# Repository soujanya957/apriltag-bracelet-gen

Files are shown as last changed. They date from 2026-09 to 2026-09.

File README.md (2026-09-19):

# apriltag-bracelet-gen

Multicolor-printable AprilTag links for a snap-together bracelet. Takes any
chain-link design (as a STEP file), stretches its flat spine to fit a real
AprilTag, and outputs a body STL (light filament) plus an insert STL (black)
per link. The joint ends are left untouched, so tag links snap into the
original, unmodified links.

Built for wrist-worn fiducial tracking (anchoring egocentric-video hand pose
to a known frame for imitation-learning data), but nothing here is specific
to that.

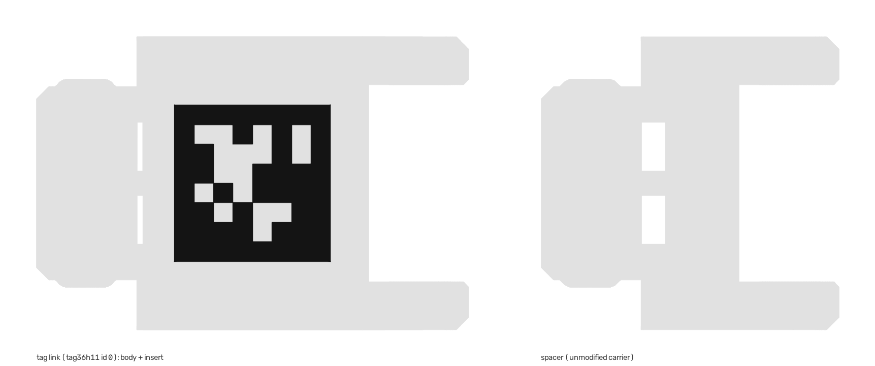
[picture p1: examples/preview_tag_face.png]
tag link next to an unmodified spacer link, seen from the tag face


*Left: generated tag link (tag36h11 id 0), light body with the black insert
flush in its pockets. Right: the unmodified carrier, exported as the spacer.*

## Quick start

```
uv venv --python 3.11 .venv && uv pip install --python .venv/bin/python -r requirements.txt
python3 -m link_gen.cli generate --carrier carriers/chainlink_v10.step \
  --profile carriers/chainlink_v10.profile.json --family tag36h11 --wrist both
```

## Docs

- [Setup](docs/setup.md) — install, get a carrier link
- [Run](docs/run.md) — generate, options, verify, choosing family/size/ids
- [Printing](docs/printing.md) — Bambu Studio multicolor workflow
- [Detection](docs/detection.md) — family, ids, pose size, `metadata.json`
- [Carriers](docs/carriers.md) — calibrate a profile for a different link design

`examples/` has one finished link (id 0 body + insert) and its metadata, to
try the print workflow without installing anything.

## Layout

```
link_gen/
  cli.py              generate / families commands
  geometry.py         CarrierProfile + cut/stretch/pocket CAD logic
  tag_source.py       fetches + caches official AprilTag bitmaps
  metadata.py         writes metadata.json per generated set
  verify.py           decodes generated inserts with a real detector
  profile_finder.py   scans a new carrier STEP to calibrate a profile
carriers/
  *.profile.json      calibration per carrier (committed)
  *.step              your carrier files (gitignored)
docs/                 guides linked above
examples/             one generated link + preview image
outputs/              generated sets (gitignored)
```

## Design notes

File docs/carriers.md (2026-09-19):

# Using a different carrier link

The tool assumes:

- both joint ends sit on either side of a flat "spine" along the carrier's
  local **X axis**;
- the spine's Y/Z cross-section is a plain constant prism (not tapered or
  filleted) across `[x_cut_left, x_cut_right]`.

## Calibrate a profile

```
python3 -m link_gen.profile_finder path/to/your_link.step
```

This slices the solid every 0.5 mm along X and prints the Y/Z cross-section
at each slice. Find the contiguous run where the cross-section stops
changing: that's the spine. Pick `x_cut_left` / `x_cut_right` safely inside
that run (not on a boundary row) and read `spine_y_min/max` and
`spine_z_min/max` off that row. Save as `carriers/your_link.profile.json`:

```json
{
  "x_cut_left": 0.5,
  "x_cut_right": 7.5,
  "spine_y_min": -12.0,
  "spine_y_max": 12.0,
  "spine_z_min": -6.0,
  "spine_z_max": 0.0,
  "solid_index": 0,
  "tag_face": "z_min"
}
```

`solid_index` picks which solid in the STEP file is the link, if it has
several.

## tag_face

Which spine face (`z_max` or `z_min`) ends up facing outward once the links
are snapped into a loop depends on the hinge design and is not derivable from
the STEP file. Generate and print one link; if the tag ends up on the inside,
flip `tag_face` in the profile and regenerate. `--tag-face` on the CLI
overrides it for one run. `chainlink_v10` needs `z_min`.

## How the geometry is built

1. Cut the carrier at `x_cut_left` and `x_cut_right`. Both joint ends are
   kept exactly as-is, so the result stays snap-compatible with unmodified
   links.
2. Bridge them with a new flat box, `extra_length` mm longer than the
   original spine.
3. Fetch the real bitmap for the requested family/id from
   [AprilRobotics/apriltag-imgs](https://github.com/AprilRobotics/apriltag-imgs)
   and cut a pocket into the tag face for every black module. Build a
   matching insert solid that fills those pockets flush.

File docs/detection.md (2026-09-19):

# Detecting the printed tags

Every generated folder has a `metadata.json` with what another machine needs.
The three values that matter:

| | tag36h11 at 16 mm (defaults) |
|---|---|
| **family** | `tag36h11` |
| **ids** | left wrist 0-7, right wrist 20-27 |
| **pose tag size** | **12.8 mm** — the black border square, *not* the 16 mm footprint (the outer 1.6 mm ring is white quiet zone). Confirm with calipers on a print. |

No key or code beyond that: AprilTag families are public and built into every
detector.

```python
# pupil-apriltags
from pupil_apriltags import Detector
det = Detector(families="tag36h11")
det.detect(gray, estimate_tag_pose=True, camera_params=(fx, fy, cx, cy), tag_size=0.0128)

# OpenCV ArUco (tag16h5 / tag25h9 / tag36h11 only)
d = cv2.aruco.getPredefinedDictionary(cv2.aruco.DICT_APRILTAG_36h11)   # markerLength=0.0128

# apriltag_ros
# tag_family: tag36h11
# standalone_tags: [{id: 0, size: 0.0128}, ...]
```

## metadata.json fields

- `generator`: git commit and the exact command line that produced the set.
- `carrier`: the STEP name, the profile used, and `spacer_file` (relative
  path to the plain-link STL).
- `link_geometry_mm`: footprint, module size, extra length, pocket depth,
  tag face.
- `detection`: family, ids, `pose_tag_size_mm`, the OpenCV dictionary name,
  and ready-to-paste snippets for pupil-apriltags / apriltag_ros / OpenCV.
- `tags[]`: files and the exact bitmap cut for each id (row 0 = top, as a
  camera sees the tag face).
- `verification`: written by `link_gen.verify`; per-id decode result and
  decision margin.

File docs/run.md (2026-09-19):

# Generate links

```
python3 -m link_gen.cli generate \
  --carrier carriers/chainlink_v10.step \
  --profile carriers/chainlink_v10.profile.json \
  --family tag36h11 \
  --wrist both
```

Writes:

```
outputs/
  spacer_chainlink_v10.stl   # unmodified carrier link, once per run
  left_wrist/                # ids 0-7:   *_body.stl, *_insert.stl, manifest.csv, metadata.json
  right_wrist/               # ids 20-27: same
```

## Options

| flag | default | meaning |
|---|---|---|
| `--wrist left\|right\|both` | `both` | which set(s) to write; each goes in `<out-dir>/<wrist>_wrist/` |
| `--ids` | left `0-7` | ids for the left (or only) wrist: range `0-7`, list `0,2,5`, or one id |
| `--right-ids` | `20-27` | ids for the right wrist |
| `--tag-size` | `16` | full tag footprint in mm, quiet zone included; must fit in `spine_len + extra_length` and `spine_width` |
| `--extra-length` | `11` | mm added to the spine. Tag links are longer than plain links; alternate with spacers to size the band |
| `--pocket-depth` | `0.4` | insert thickness in mm; 0.3–0.5 for a 0.4 mm nozzle |
| `--tag-face z_max\|z_min` | from profile | which spine face gets the tag; see [carriers.md](carriers.md) |
| `--out-dir` | `outputs` | output root |

`python3 -m link_gen.cli families` lists the supported families.

## Verify

Rasterizes each insert as a camera would see the printed face and runs a real
AprilTag detector on it. Catches mirroring or module-size mistakes before you
print. Results are written into that folder's `metadata.json`.

```
python3 -m link_gen.verify outputs/left_wrist
python3 -m link_gen.verify outputs/right_wrist
```

## Choosing a family, size, and ids

- `tag36h11` is the safe default: best false-positive rejection, which
  matters when footage is processed unsupervised.
- `tag25h9` has a simpler pattern; worth trying if motion blur is the limit
  (fast wrist movement, camera close and moving).
- Keep modules ≥ ~1.2 mm on a 0.4 mm nozzle. A 10×10 family at 16 mm gives
  1.6 mm modules; below ~12 mm total you're fighting print resolution.
- Give every link a unique id and reserve a separate block per wrist
  (left 0-7, right 20-27) so one visible tag tells you which wrist it is.

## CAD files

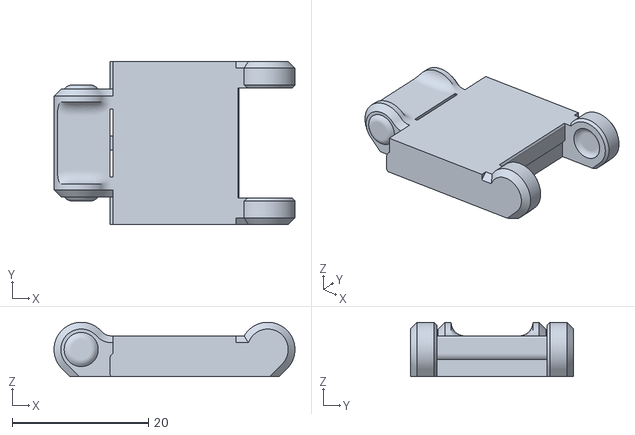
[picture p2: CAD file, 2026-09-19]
examples/link_tag36h11_000_body.stl
35.4 x 24.0 x 8.00

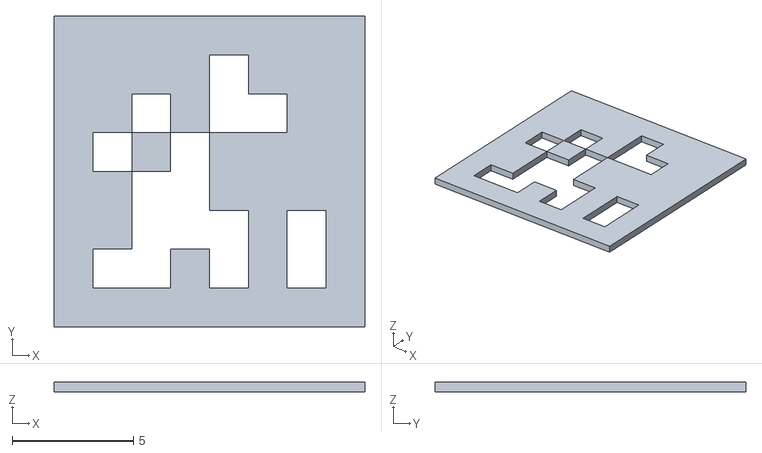
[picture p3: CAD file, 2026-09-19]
examples/link_tag36h11_000_insert.stl
12.8 x 12.8 x 0.4

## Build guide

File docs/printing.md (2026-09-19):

# Printing (Bambu Studio / any AMS slicer)

STL has no color. Each link is two files that share one coordinate origin:
`_body.stl` (light filament) and `_insert.stl` (black). Importing the insert
as a *part* of the body is what makes the slicer print them as one object in
two colors.

Per link:

1. **File → Import** the `_body.stl`.
2. Right-click the body in the object list → **Add part → Load...** → pick
   the matching `_insert.stl`. It lands already aligned. Do not move it.
3. Expand the object; set the body's filament to white/light grey and the
   insert part's to black.
4. If the profile's `tag_face` is `z_min` (it is for `chainlink_v10`), the tag
   is on the face that sits on the plate. Either flip the object (select →
   **F**) so the tag faces up, or print it face-down on a textured PEI plate
   for a matte tag surface. Both work; the tag face is fully planar.
5. Import `spacer_<carrier>.stl`, set the light filament, and duplicate it as
   many times as the band needs.
6. **Arrange**, slice at 0.2 mm layers (0.4 mm pocket = 2 black layers), no
   supports. Scrub to the tag layers in the preview to check the pattern.

Print one tag link first: check it snaps into a spacer with the tag facing
outward, and that a phone camera decodes it. Then run the batch.

Matte filament (matte PLA or PETG) beats glossy: glare at oblique angles is a
more common detection failure than resolution.

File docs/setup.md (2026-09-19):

# Setup

## Install

Python 3.10–3.12 (cadquery does not support 3.13+ yet).

```
uv venv --python 3.11 .venv
uv pip install --python .venv/bin/python -r requirements.txt
```

or with plain pip: `pip install -r requirements.txt`. `cadquery` pulls in an
OCCT geometry kernel and takes a few minutes the first time.

Optional, only for `link_gen.verify` (decodes the generated tags with a real
detector):

```
uv pip install --python .venv/bin/python pupil-apriltags opencv-python-headless trimesh
```

## Get a carrier link

This repo does **not** bundle a carrier STEP file: bracelet/chain-link models
are usually someone else's design with its own license. Bring your own and
put it under `carriers/` (gitignored, so you won't commit it by accident).

`carriers/chainlink_v10.profile.json` is calibrated for the free
"Chain Link Bracelet" snap-link design (single roller boss + forked double
roller hinge, flat spine between them). Download that model, save it as
`carriers/chainlink_v10.step`, and you're ready to [run](run.md).

Using a different link design? See [carriers.md](carriers.md).

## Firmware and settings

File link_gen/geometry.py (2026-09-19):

"""
Turns a "carrier" bracelet link (any snap/hinge link design, given as a
STEP file) into a multicolor-printable AprilTag link, by:

  1. Cutting the carrier at two X planes that bound a flat, constant
     cross-section "spine" region between its two joint ends.
  2. Replacing that spine with a longer flat box (so there's room for a
     tag), while leaving both original joint ends completely untouched
     -- this is what keeps the result snap-compatible with your other,
     unmodified links.
  3. Cutting shallow pockets into the new spine's top face everywhere
     the tag bitmap is black, and building a matching "insert" solid
     that plugs those pockets flush.

You print `body` in one filament color and `insert` in another (Bambu
Studio: load both STLs, Add Part the insert onto the body, assign
filament colors per-part -- they already share the same coordinate
origin, so no repositioning is needed).

IMPORTANT ASSUMPTIONS (see profile_finder.py to check these for a new
carrier):
  - The two joint ends sit on either side of the spine along the
    carrier's local X axis.
  - The spine's cross-section (Y and Z extent) is constant across the
    whole [x_cut_left, x_cut_right] range -- i.e. it's a plain prism,
    not tapered or filleted. profile_finder.py's `scan` command will
    show you this directly for your file.
"""
from __future__ import annotations

import json
import pathlib
from dataclasses import dataclass

import cadquery as cq
from cadquery import Solid, Vector
import numpy as np

from .tag_source import TagBitmap


@dataclass
class CarrierProfile:
    """Geometric calibration for one carrier link design.  Create one of
    these per bracelet/link model you want to use -- see
    profile_finder.py to help measure x_cut_left / x_cut_right for a
    new STEP file, and just read the Y/Z bounding box of the flat
    region for the rest.
    """
    x_cut_left: float     # end of the left joint end / start of flat spine
    x_cut_right: float    # start of the right joint end / end of flat spine
    spine_y_min: float
    spine_y_max: float
    spine_z_min: float
    spine_z_max: float    # top of the spine -- tag pockets are cut down from here
    solid_index: int = 0  # which Solids()[i] in the STEP file is the link
    tag_face: str = "z_max"  # which spine face is outward once assembled: z_max | z_min

    @classmethod
    def from_json(cls, path: str | pathlib.Path) -> "CarrierProfile":
        data = json.loads(pathlib.Path(path).read_text())
        return cls(**data)

    def to_json(self, path: str | pathlib.Path) -> None:
        pathlib.Path(path).write_text(json.dumps(self.__dict__, indent=2))

    @property
    def spine_len(self) -> float:
        return self.x_cut_right - self.x_cut_left

    @property
    def spine_width(self) -> float:  # Y extent
        return self.spine_y_max - self.spine_y_min

    @property
    def spine_thickness(self) -> float:  # Z extent
        return self.spine_z_max - self.spine_z_min


def load_carrier_solid(step_path: str | pathlib.Path, profile: CarrierProfile) -> cq.Solid:
    r = cq.importers.importStep(str(step_path))
    solids = r.val().Solids()
    return solids[profile.solid_index]


def _half_space(xmin: float, xmax: float, pad: float = 200.0) -> Solid:
    return Solid.makeBox(xmax - xmin, pad, pad, Vector(xmin, -pad / 2, -pad / 2))


def _fuse_all(solids: list[Solid]) -> Solid:
    out = solids[0]
    for s in solids[1:]:
        out = out.fuse(s)
    return out


def build_tag_link(
    carrier: Solid,
    profile: CarrierProfile,
    tag: TagBitmap,
    tag_size_mm: float,
    extra_length_mm: float,
    pocket_depth_mm: float = 0.4,
    tag_face: str = "z_max",
) -> tuple[Solid, Solid]:
    """
    Returns (body_solid, insert_solid).

    tag_size_mm is the full footprint of the tag bitmap (including its
    built-in white quiet zone) -- it must fit within
    profile.spine_len + extra_length_mm, and within profile.spine_width,
    or this raises ValueError.

    tag_face: "z_max" (default) cuts the tag into the spine's top face
    (profile.spine_z_max); "z_min" cuts it into the bottom face instead
    (profile.spine_z_min). Which one is physically "outward" once links
    are snapped into a curved bracelet depends on your carrier's local
    axes and hinge direction -- if a printed link comes out with the tag
    facing inward/downward, this is the one setting to flip. It doesn't
    change x_cut_left/x_cut_right or anything about the joint ends.
    """
    if tag_face not in ("z_max", "z_min"):
        raise ValueError(f"tag_face must be 'z_max' or 'z_min', got {tag_face!r}")
    new_spine_len = profile.spine_len + extra_length_mm
    if tag_size_mm > new_spine_len or tag_size_mm > profile.spine_width:
        raise ValueError(
            f"tag_size_mm={tag_size_mm} doesn't fit the spine "
            f"({new_spine_len:.1f} x {profile.spine_width:.1f} mm available). "
            f"Increase extra_length_mm or shrink the tag."
        )

    left_piece = carrier.intersect(_half_space(-200, profile.x_cut_left))
    right_piece = carrier.intersect(_half_space(profile.x_cut_right, 200))
    right_piece = right_piece.translate((extra_length_mm, 0, 0))

    spine_box = Solid.makeBox(
        new_spine_len,
        profile.spine_width,
        profile.spine_thickness,
        Vector(profile.x_cut_left, profile.spine_y_min, profile.spine_z_min),
    )

    body = left_piece.fuse(spine_box).fuse(right_piece).clean()

    grid = tag.grid
    n = grid.shape[0]
    module = tag_size_mm / n

    spine_center_x = profile.x_cut_left + new_spine_len / 2.0
    x0 = spine_center_x - tag_size_mm / 2.0
    y0 = -tag_size_mm / 2.0
    if tag_face == "z_max":
        pocket_z = profile.spine_z_max - pocket_depth_mm - 0.01
        insert_z = profile.spine_z_max - pocket_depth_mm
    else:
        pocket_z = profile.spine_z_min - 0.01
        insert_z = profile.spine_z_min

    pocket_boxes, insert_boxes = [], []
    for row in range(n):
        for col in range(n):
            if not grid[row, col]:
                continue
            px = x0 + col * module
            # PNG row 0 is the top of the image. Looking at the z_max face
            # from +Z, +Y is up, so rows must be flipped or the tag comes out
            # mirrored; looking at the z_min face from -Z, +Y is down, so
            # rows map straight through.
            py = y0 + ((n - 1 - row) if tag_face == "z_max" else row) * module
            pocket_boxes.append(
                Solid.makeBox(module, module, pocket_depth_mm + 0.02,
                               Vector(px, py, pocket_z))
            )
            insert_boxes.append(
                Solid.makeBox(module, module, pocket_depth_mm,
                               Vector(px, py, insert_z))
            )

    if not pocket_boxes:
        raise ValueError("Tag bitmap has no black modules -- check the fetched bitmap.")
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
